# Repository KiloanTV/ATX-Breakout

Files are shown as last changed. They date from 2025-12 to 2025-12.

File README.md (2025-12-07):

<div>
  <h1 align="center">ATX Breakout</h1>

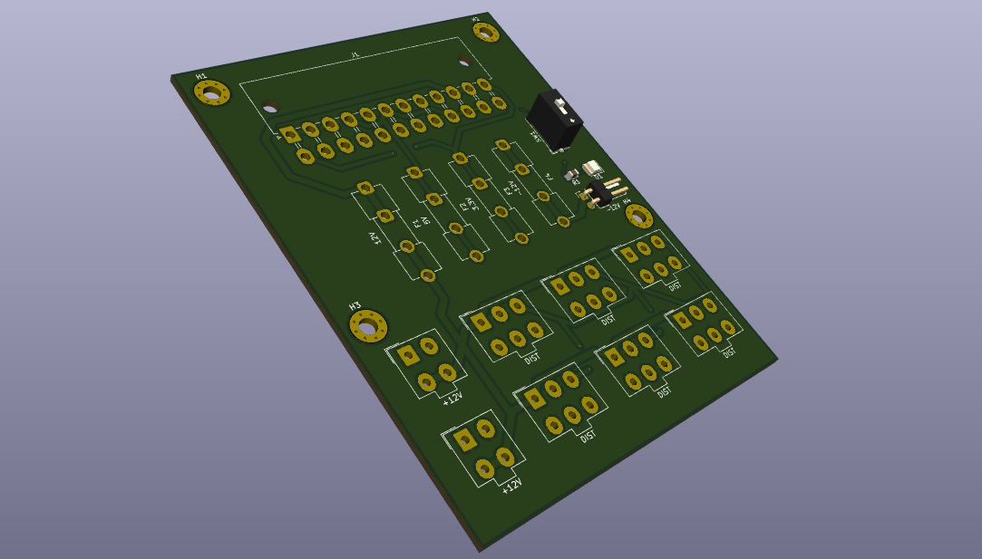
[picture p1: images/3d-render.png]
ATX-Breakout
  

  <p align="center">
  <a href="https://blueprint.hackclub.com/">
    
  </a>
  </p>
  <h1></h1>
  <p align="center">
    A simple ATX Breakout-Board to Power 12V 5V and 3V3 Devices from an standart PC Powersupply.
  </p>
</div>

<sub align="center">This work is licensed under the
[MIT License](https://mit-license.org).
</sub>

## Table of Contents

- [About](#about)
- [Pictures](#pictures)
- [Bill of Materials](#bill-of-materials)

# About

I have a dream, a hole system of electronics and devices for the live event industry to learn to develop mixing consoles and other systems. so this is one of the base components for everything i will make in the future. I will use this board as a power distribution board to supply power to the internal electronic devices in the Kiloan Desk chassis for now.

# Pictures

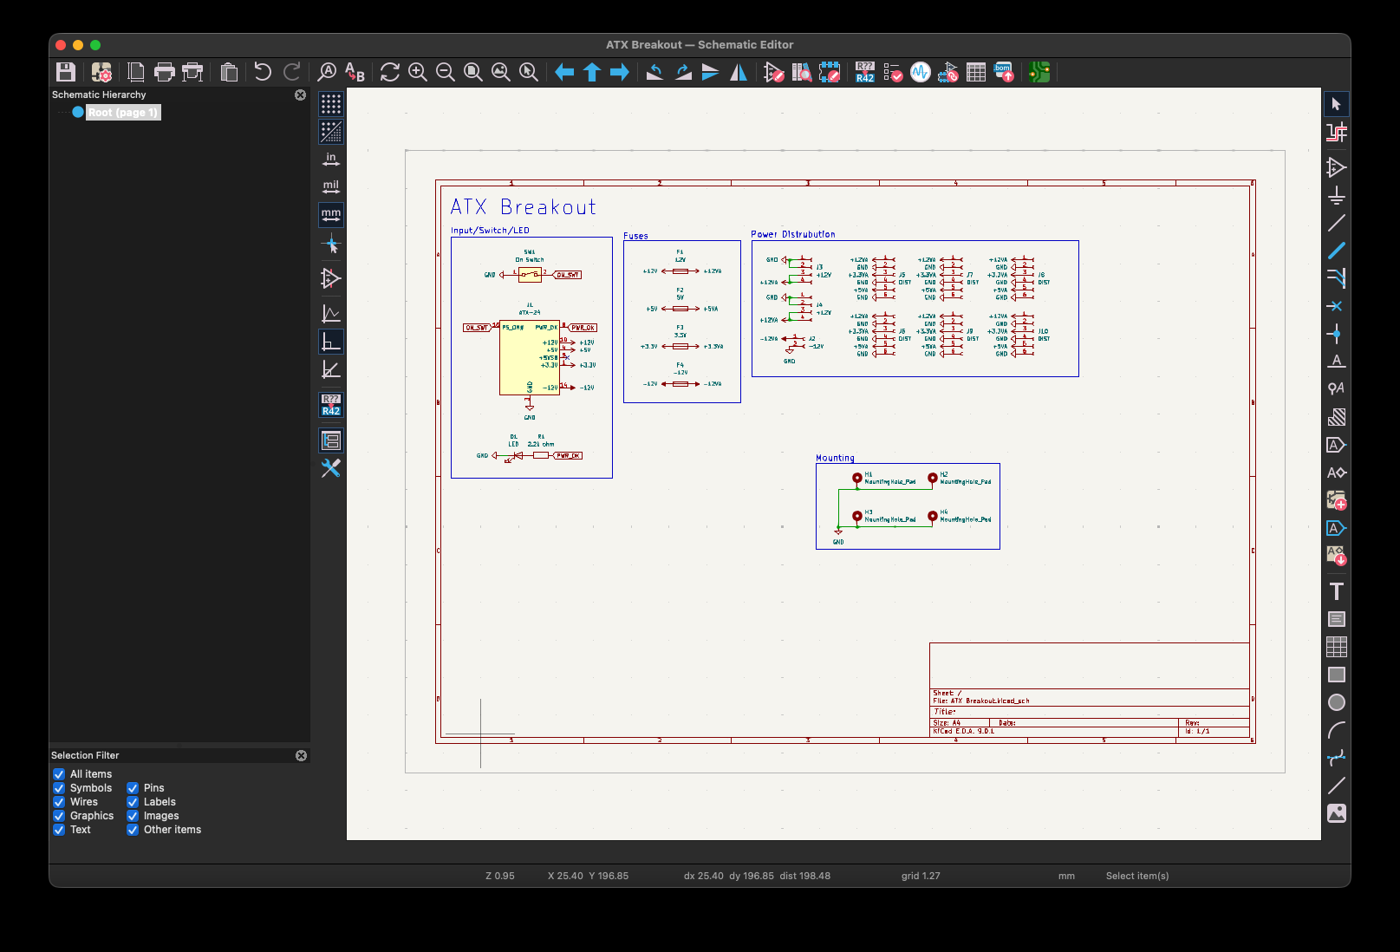
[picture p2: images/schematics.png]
schematics


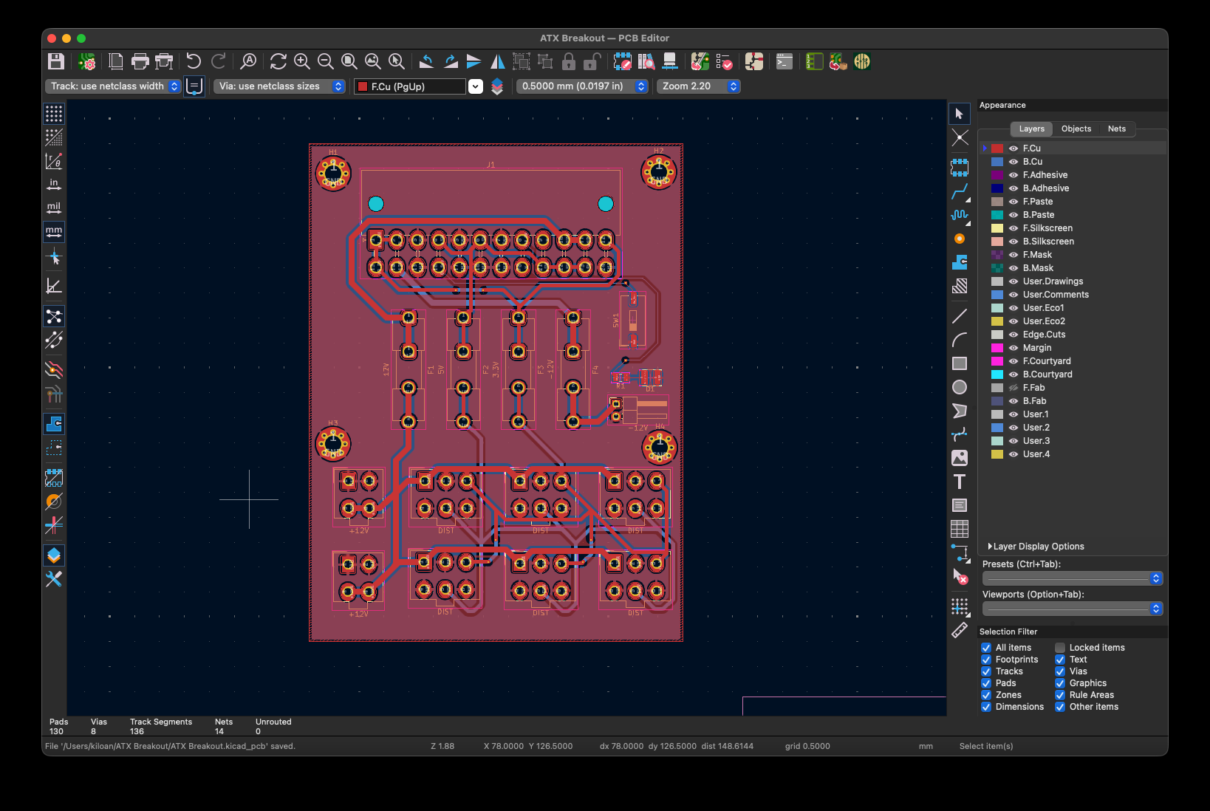
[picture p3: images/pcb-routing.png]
pcb-routing


# Bill of Materials

<details>
<summary><strong>Show Bill Of Materials(BOM) ----></strong></summary>

|Designator |Footprint |Quantity|Value |LCSC Part #|
|---|---|---|---|---|
|D1 |1210 |1 |LED |C601676 |
|F1 |Fuseholder_Clip-5x20mm_Eaton_1A5601-01_Inline_P20.80x6.76mm_D1.70mm_Horizontal|1 |12V |C3206715 |
|F2 |Fuseholder_Clip-5x20mm_Eaton_1A5601-01_Inline_P20.80x6.76mm_D1.70mm_Horizontal|1 |5V |C3206715 |
|F3 |Fuseholder_Clip-5x20mm_Eaton_1A5601-01_Inline_P20.80x6.76mm_D1.70mm_Horizontal|1 |3.3V |C3206715 |
|F4 |Fuseholder_Clip-5x20mm_Eaton_1A5601-01_Inline_P20.80x6.76mm_D1.70mm_Horizontal|1 |-12V |C3206715 |
|J1 |Molex_Mini-Fit_Jr_5569-24A2_2x12_P4.20mm_Horizontal |1 |ATX-24 |C492361 |
|J10, J5, J6, J7, J8, J9|Molex_Mini-Fit_Jr_5566-06A_2x03_P4.20mm_Vertical |6 |DIST |C471417 |
|J2 |PinHeader_1x02_P2.54mm_Horizontal |1 |-12V |C492401 |
|J3, J4 |Molex_Mini-Fit_Jr_5566-04A_2x02_P4.20mm_Vertical |2 |+12V |C293502 |
|R1 |0805 |1 |2.2k ohm |C17520 |
|SW1 |SW_DIP_SPSTx01_Slide_9.78x4.72mm_W8.61mm_P2.54mm |1 |On Switch|C3293151 |
|JLCPCB Quote: 6.54 Dollar| | | | |
|LCSC Quote: 26.14 Dollar | | | | |
|Quote: 32.68 Dollar | | | | |

</details>

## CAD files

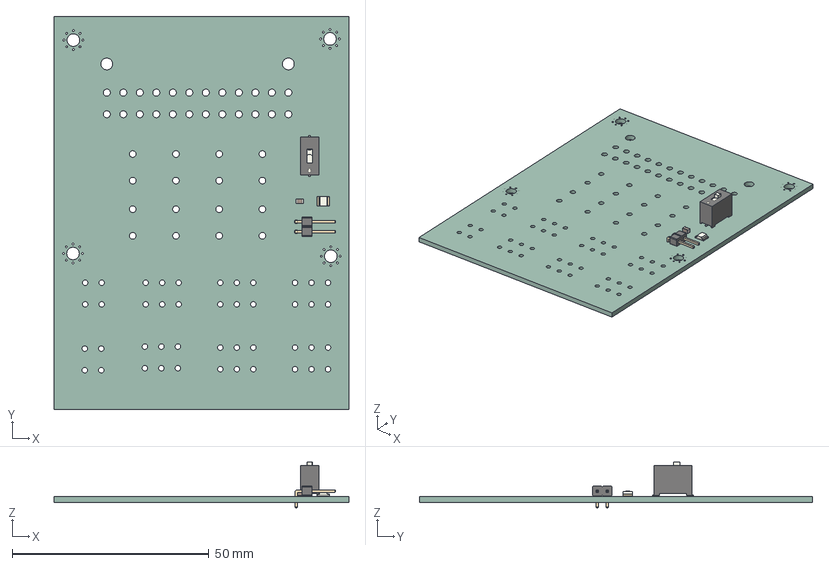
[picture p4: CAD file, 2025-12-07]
ATX Breakout.step
75.0 x 100.0 x 11.6 mm
SW_DIP_SPSTx01_Slide_9.78x4.72mm_W8.61mm_P2.54mm
LED_1210_3225Metric
C_0805_2012Metric
PinHeader_1x02_P2.54mm_Horizontal
ATX Breakout_PCB

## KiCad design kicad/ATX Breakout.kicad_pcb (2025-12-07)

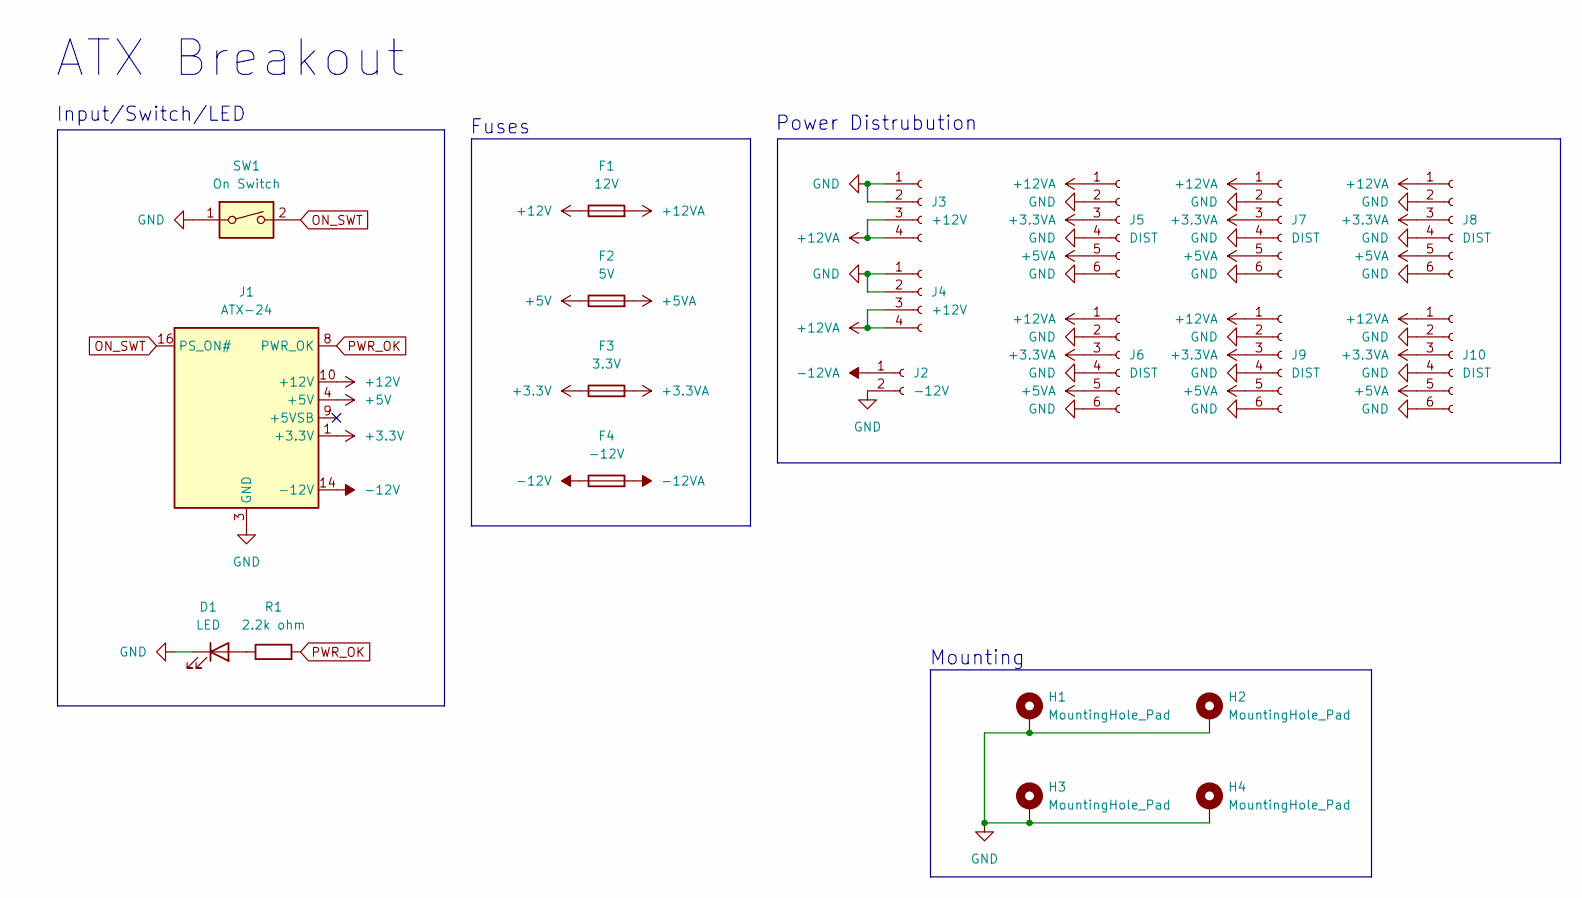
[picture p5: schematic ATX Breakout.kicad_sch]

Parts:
D1: LED; LED_1210_3225Metric; LCSC C601676
F1: 12V; Fuseholder_Clip-5x20mm_Eaton_1A5601-01_Inline_P20.80x6.76mm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; LCSC C3206715
F2: 5V; Fuseholder_Clip-5x20mm_Eaton_1A5601-01_Inline_P20.80x6.76mm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; LCSC C3206715
F3: 3.3V; Fuseholder_Clip-5x20mm_Eaton_1A5601-01_Inline_P20.80x6.76mm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; LCSC C3206715
F4: -12V; Fuseholder_Clip-5x20mm_Eaton_1A5601-01_Inline_P20.80x6.76mm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; LCSC C3206715
H1, H2, H3, H4: MountingHole_Pad; MountingHole_3.2mm_M3_Pad_Via
J1: ATX-24; Molex_Mini-Fit_Jr_5569-24A2_2x12_P4.20mm_Horizontal; LCSC C492361
J2: -12V; PinHeader_1x02_P2.54mm_Horizontal; LCSC C492401
J3, J4: +12V; Molex_Mini-Fit_Jr_5566-04A_2x02_P4.20mm_Vertical; LCSC C293502
J5, J6, J7, J8, J9, J10: DIST; Molex_Mini-Fit_Jr_5566-06A_2x03_P4.20mm_Vertical; LCSC C471417
R1: 2.2k ohm; C_0805_2012Metric_Pad1.18x1.45mm_HandSolder; LCSC C17520
SW1: On Switch; SW_DIP_SPSTx01_Slide_9.78x4.72mm_W8.61mm_P2.54mm; LCSC C3293151

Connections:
+3.3V: F3.1, J1.1 (+3.3V), J1.2 (+3.3V), J1.12 (+3.3V), J1.13 (+3.3V)
+3.3VA: F3.2, J5.3, J6.3, J7.3, J8.3, J9.3, J10.3
+5V: F2.1, J1.4 (+5V), J1.6 (+5V), J1.21 (+5V), J1.22 (+5V), J1.23 (+5V)
+5VA: F2.2, J5.5, J6.5, J7.5, J8.5, J9.5, J10.5
+12V: F1.1, J1.10 (+12V), J1.11 (+12V)
+12VA: F1.2, J3.3, J3.4, J4.3, J4.4, J5.1, J6.1, J7.1, J8.1, J9.1, J10.1
-12V: F4.1, J1.14 (-12V)
-12VA: F4.2, J2.1
GND: D1.1 (K), H1.1, H2.1, H3.1, H4.1, J1.3 (GND), J1.5 (GND), J1.7 (GND), J1.15 (GND), J1.17 (GND), J1.18 (GND), J1.19 (GND), J1.24 (GND), J2.2, J3.1, J3.2, J4.1, J4.2, J5.2, J5.4, J5.6, J6.2, J6.4, J6.6, J7.2, J7.4, J7.6, J8.2, J8.4, J8.6, J9.2, J9.4, J9.6, J10.2, J10.4, J10.6, SW1.1
unnamed: D1.2 (A), R1.1
ON_SWT: J1.16 (PS_ON#), SW1.2
PWR_OK: J1.8 (PWR_OK), R1.2

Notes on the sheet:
Input/Switch/LED
Power Distrubution
Mounting
ATX Breakout
Fuses

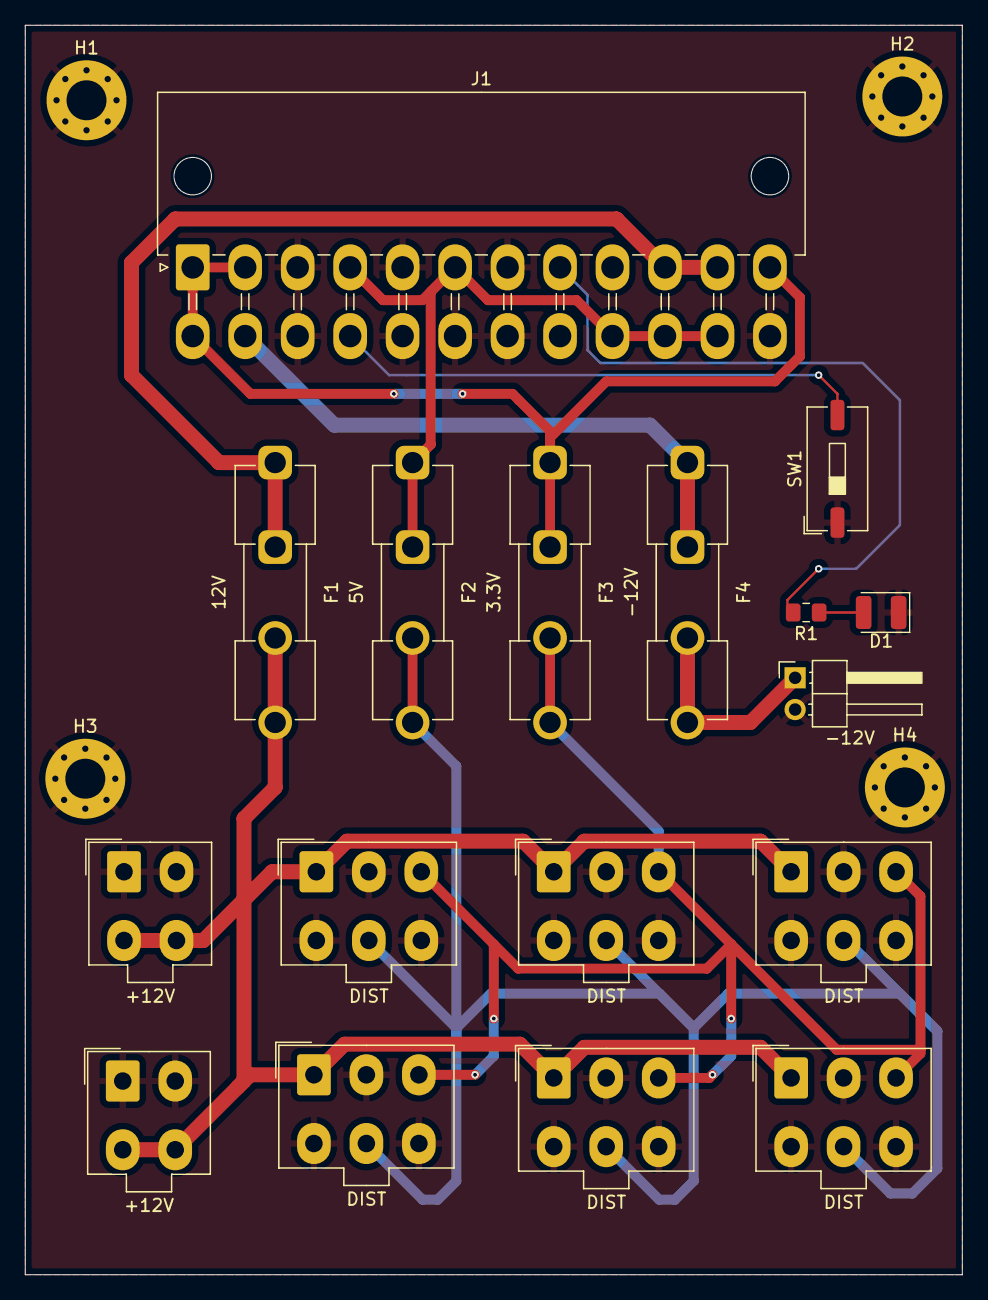
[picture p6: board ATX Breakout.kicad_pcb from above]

Board: 2 copper layers, 75.0 x 100.0 mm, 21 parts (0 on the bottom side), 12 nets.

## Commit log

2025-12-07 add all files
    _ Kian
    [ATX Breakout.kicad_pcb, ATX Breakout.kicad_sch, bom.csv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]
2025-12-07 add 3d modell
    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
    [ATX Breakout.step]
